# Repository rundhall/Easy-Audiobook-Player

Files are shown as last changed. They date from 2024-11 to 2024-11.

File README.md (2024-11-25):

# Easy Audiobook Player

## Introduction
The **Easy Audiobook Player** is a simple, user-friendly device designed for individuals who face challenges using modern gadgets. Originally created as a Christmas gift for my 94-year-old grandmother, this device is tailored for users with visual or physical impairments, providing an accessible solution for audiobook playback.

---

## Features
- **Single Button Operation**: Simple start/stop functionality.
- **Advanced Controls**:
  - 5-second press: Skip to the next audiobook file.
  - 20-second press: Restart playback from the beginning.
- **Resume Playback**: Automatically resumes from the last played position.

---

## Components

| Component | Quantity | Link | Price  |
|---|---|---|---|
| DC 12V 24V 80W x 2 Audio Amplifier Board | 1 | [Link](https://www.aliexpress.com/item/32823374190.html) | $2.91  |
| Arduino Nano 16MHz ATMEGA328P | 1 | [Link](https://www.aliexpress.com/item/1005006472755752.html) | $3.32  |
| DFPlayer Mini MP3 Module | 1 | [Link](https://www.aliexpress.com/item/4000379417594.html) | $1.63  |
| Game Push Button Switch | 1 | [Link](https://www.aliexpress.com/item/1005006347986280.htm) | $0.50  |
| Wooden Enclosure Box (16x10x9.2 cm) | 1 | [Link](https://www.aliexpress.com/item/1005005854034476.html) | $4.94  |
| Toggle Switch SS22D07 2P2T | 1 | [Link](https://www.aliexpress.com/item/32822779479.html) | $0.91  |
| USB 2.0 A Power Supply Extension Cable | 1 | [Link](https://www.aliexpress.com/item/1005004980471643.html) | $0.56  |
| DC-DC Voltage Regulator Module LM2596S | 1 | [Link](https://www.aliexpress.com/item/1005001691110030.html) | $0.72  |
| GHXAMP Full Range Speakers (4 ohm, 16W) | 2 | [Link](https://www.aliexpress.com/item/1005007219657143.html) | $7.31  |
| Mini Screw Terminal Blocks | 1 | [Link](https://www.aliexpress.com/item/1005005433827504.html) | $0.72  |
| Micro SD Card (max. 32 GB) | 1 | [Link](https://www.aliexpress.com/item/1005001617961938.html) | $2.57  |
| PCB | 1 | Custom | ~$10.00 |

**Total Material Cost**: $36.09

---

## Assembly
### Hardware
1. **Connect Components**: Use a custom PCB or breadboard for wiring the Arduino Nano, DFPlayer Mini, and amplifier board.
2. **Enclosure**:
   - Drill holes for the speaker, button, and cable entry.
   - Mount all components securely in the wooden box.
3. **Power Supply**: Feed the USB power cable through the enclosure and connect to a 5V charger.

### Software
#### Preparing MP3 Files
1. Place your audiobook MP3 files into a `mp3_files` folder.
2. Use the provided Python script (`mp3_to_mp3chunks.bat`) to split files into 5-minute chunks.
3. Copy the output files to the `01` folder on a FAT32-formatted SD card.

#### Programming the Arduino
1. Install [PlatformIO](https://platformio.org/) in Visual Studio Code.
2. Clone the repository and open the `EasyAudiobookPlayer_Arduino` project.
3. Update the `platformio.ini` file to match your Arduino Nano configuration.
4. Upload the code to the Arduino Nano using PlatformIO.

---

## How It Works
- **Playback**: The Arduino controls the DFPlayer Mini to play audio files stored on the SD card.
- **Amplification**: The audio signal is amplified and played through the speakers.
- **Power Management**: A DC-DC converter steps up voltage for the amplifier, while the Arduino and DFPlayer operate on 5V.

---

## Usage Instructions
1. Press the button to start or stop playback.
2. Hold for 5 seconds to skip to the next file.
3. Hold for 20 seconds to reset playback.
4. Enjoy your audiobook!

---

## Conclusion
This Easy Audiobook Player is a thoughtful gift for anyone who values simplicity and accessibility. Whether for a loved one or as a DIY project, it’s a functional and meaningful creation.

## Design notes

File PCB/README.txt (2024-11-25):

# PCB for the Easy Audiobook Player

This is the wiring diagram and PCB plan for Easy Audiobook Player project to make this project even easier to build.

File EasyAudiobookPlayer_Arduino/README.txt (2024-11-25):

EasyAudiobookPlayer project Arduino modul programing. 

## Programming the Arduino Module  

### Requirements  
- A USB cable to connect the Arduino module to your computer.  
- Visual Studio Code with the PlatformIO add-on installed.  
- The EasyAudiobookPlayer Arduino project files from GitHub.  

---

### Steps to Upload the Program  
1. Download the Project  
   - Clone or download the EasyAudiobookPlayer Arduino project files from GitHub.  

2. Install Required Software  
   - Install [Visual Studio Code](https://code.visualstudio.com/).  
   - Open Visual Studio Code and install the PlatformIO add-on.  

3. Open the Project  
   - Open the `EasyAudiobookPlayer_Arduino` directory in Visual Studio Code.  

4. Configure PlatformIO  
     - Open the `platformio.ini` file in the project directory.  
   - Modify the configuration to match your Arduino module type and serial port:  
	"[env:nanoatmega328]
	platform = atmelavr
	board = nanoatmega328
	framework = arduino
	monitor_speed = 115200
	lib_deps = 	
		xoseperez/DebounceEvent@^2.0.5
		prosenb/EEPROMWearLevel@^2.1.0
		dfrobot/DFRobotDFPlayerMini@^1.0.6 “
 - Replace ` nanoatmega328` with the correct Arduino model (e.g., `pro16MHzatmega328`).  
 - Add this line: upload_port = your_serial_port if you know the serial port belongs to the Arduiono. Replace `your_serial_port` with the appropriate COM port (e.g., `COM3` on Windows).  

5. Modify the Source Code (Optional)  
   - If needed, edit the file `EasyAudiobookPlayer_Arduino\src\main.cpp` to customize the functionality.  

6. Upload the Program  
   - Connect the Arduino module to your computer via USB.  
   - In Visual Studio Code, click the PlatformIO: Upload button or use the shortcut to upload the program to the Arduino.  

---

### Program Overview  
The program is structured as follows:  

1. Initialization in `setup()`  
   - The MP3 player module is initialized.  
   - Button press functionality is configured.  

2. Looping in `loop()`  
   - Continuously monitors:  
     - Button presses:  
       - Toggles between play and pause modes.  
     - MP3 playback status:  
       - If an MP3 finishes, the program:  
         - Saves the current MP3 sequence number to the EEPROM.  
         - Ensures playback can resume from this sequence number upon restarting the device.  

---

### Notes  
- Ensure the Arduino module is compatible with the selected settings in the `platformio.ini` file.  
- The program uses the EEPROM to save and retrieve the MP3 sequence number, allowing it to resume playback seamlessly after a power cycle or reset.  

--- 

This README should guide you through the upload process and provide an understanding of the program's functionality. Let me know if you need further clarifications or enhancements!

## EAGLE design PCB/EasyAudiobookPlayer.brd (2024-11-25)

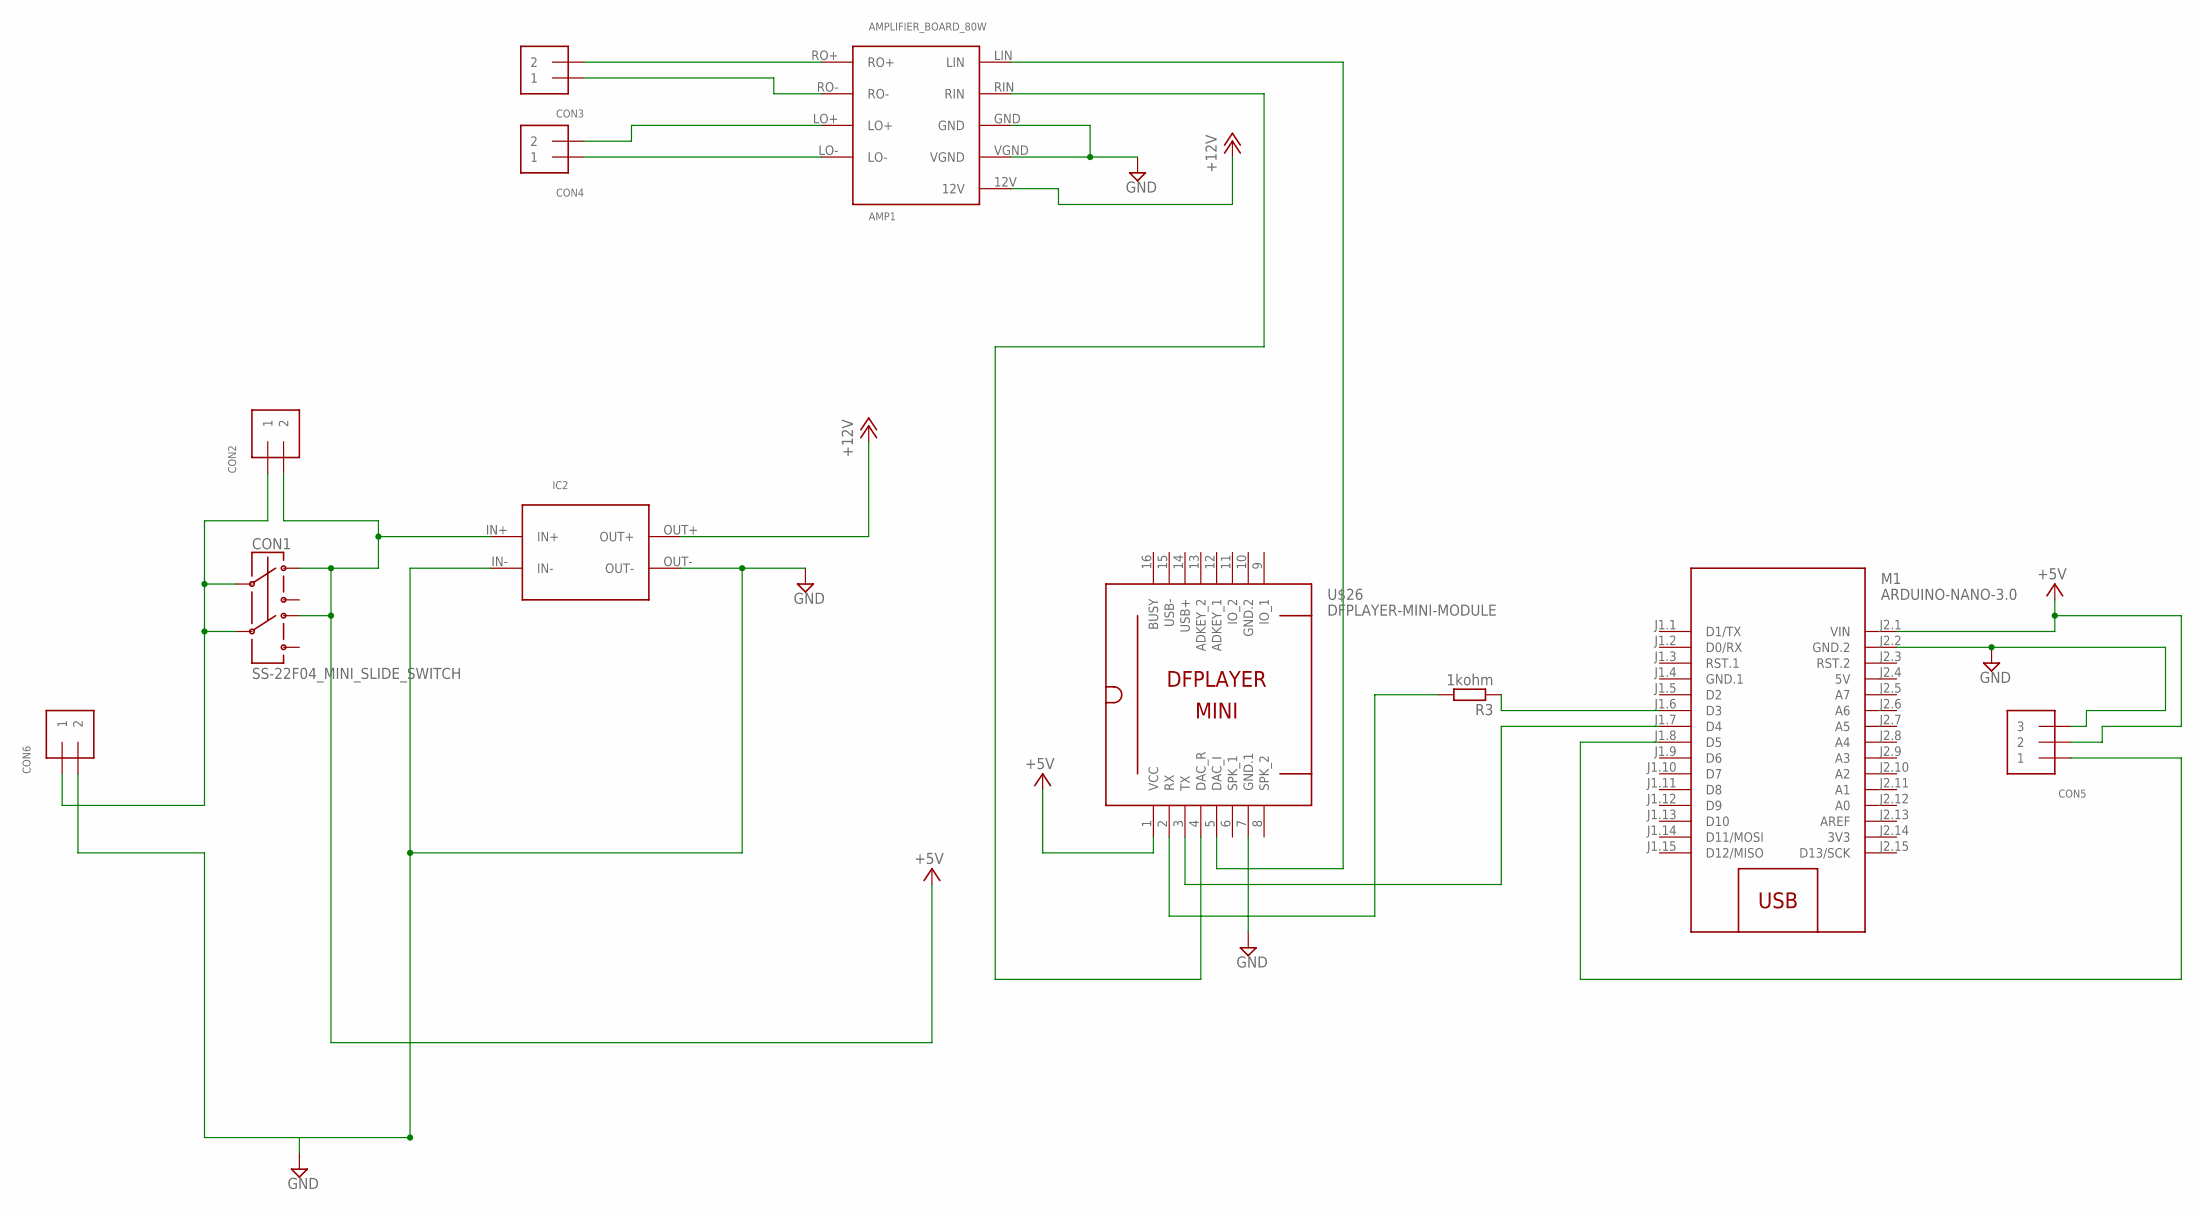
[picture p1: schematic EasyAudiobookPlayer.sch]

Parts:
AMP1: AMPLIFIER_BOARD_80W
CON1: SS-22F04_MINI_SLIDE_SWITCH
CON2, CON3, CON4, CON6: 1X2_5MM_TERMINAL_BLOCK
CON5: 1X3_5MM_TERMINAL_BLOCK
IC2: XL6009_STEP_UP_CONVERTER_MODULE
M1: ARDUINO-NANO-3.0
R3: 1kohm; M1206
U$26: DFPLAYER-MINI-MODULE

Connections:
3V3: M1.J2.14 (3V3)
5V: M1.J2.4 (5V)
+5V: CON1.O1_2, CON1.O2_2, CON2.2, CON5.2, IC2.IN+, M1.J2.1 (VIN), U$26.1 (VCC)
+12V: AMP1.12V, IC2.OUT+
GND: AMP1.GND, AMP1.VGND, CON5.3, CON6.2, IC2.IN-, IC2.OUT-, M1.J2.2 (GND.2), U$26.7 (GND.1)
GND.1: M1.J1.4 (GND.1)
GND.2: U$26.10 (GND.2)
unnamed: CON1.I1_1, CON1.I2_1, CON2.1, CON6.1
unnamed: AMP1.RO+, CON3.2
unnamed: AMP1.RO-, CON3.1
unnamed: AMP1.LO+, CON4.2
unnamed: AMP1.LO-, CON4.1
unnamed: M1.J1.6 (D3), R3.1
unnamed: R3.2, U$26.2 (RX)
unnamed: M1.J1.7 (D4), U$26.3 (TX)
unnamed: AMP1.RIN, U$26.4 (DAC_R)
unnamed: AMP1.LIN, U$26.5 (DAC_I)
unnamed: CON5.1, M1.J1.8 (D5)

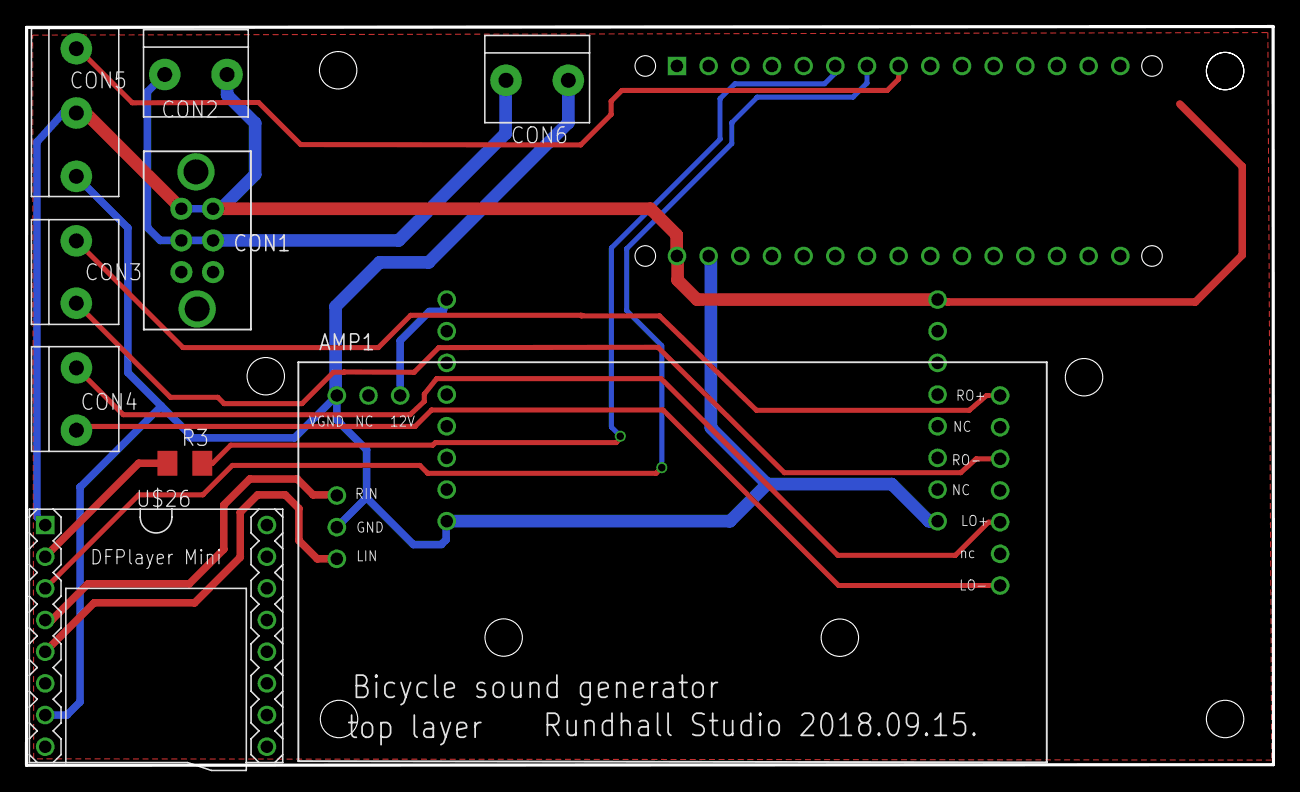
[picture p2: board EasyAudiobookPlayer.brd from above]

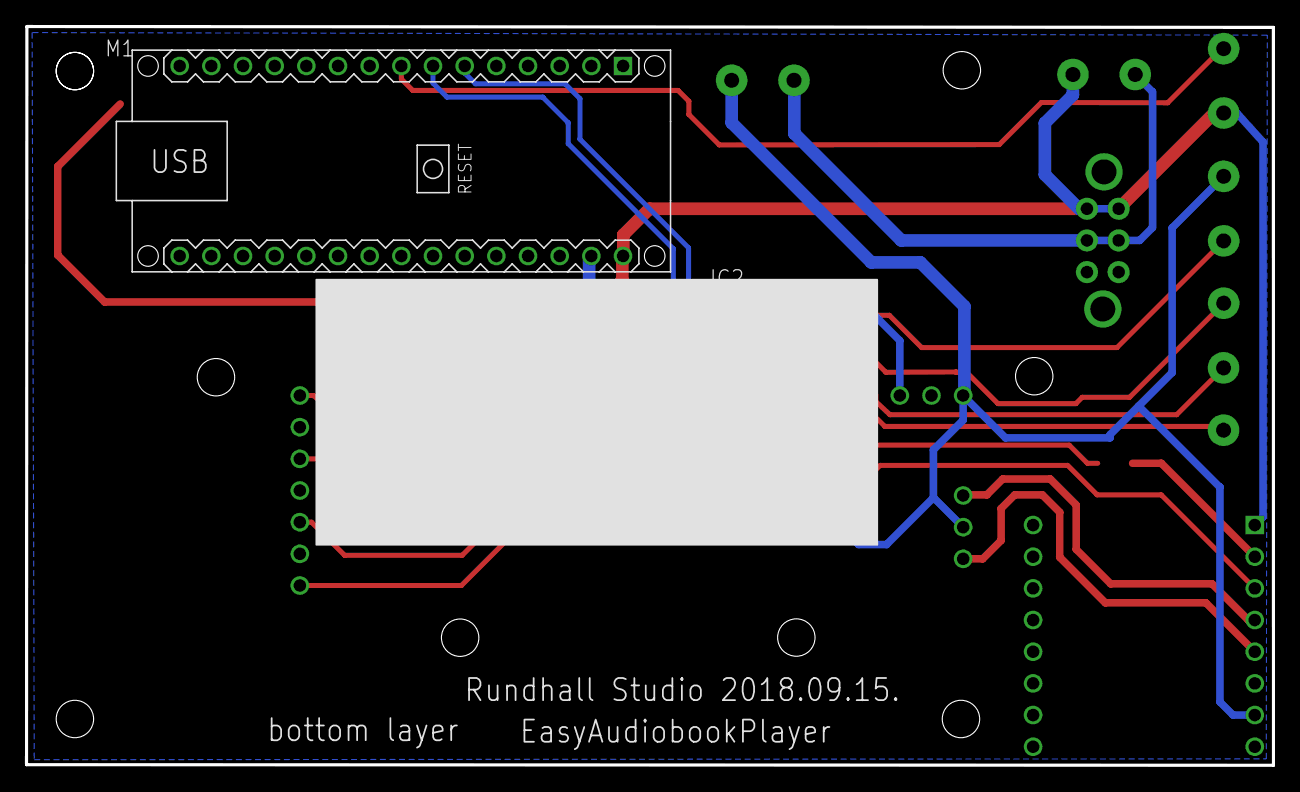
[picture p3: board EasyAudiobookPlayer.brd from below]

Board: 4 copper layers, 100.0 x 59.3 mm, 11 parts (2 on the bottom side), 14 nets.

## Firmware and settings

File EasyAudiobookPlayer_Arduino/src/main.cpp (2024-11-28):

#include "Arduino.h"
#include "SoftwareSerial.h"
#include "DFRobotDFPlayerMini.h"
#include <EEPROM.h>
#include <DebounceEvent.h>
#include <EEPROMWearLevel.h>
#define BUTTON_PIN 5
#define LED 13

SoftwareSerial mySoftwareSerial(4, 3); // RX, TX
DFRobotDFPlayerMini myDFPlayer;
// See https://github.com/PRosenb/EEPROMWearLevel
#define EEPROM_LAYOUT_VERSION 0
#define AMOUNT_OF_INDEXES 2
#define INDEX_CONFIGURATION_VAR1 0



bool isPlaying = false;
int currentFile = 1;


void saveState() {
  EEPROMwl.put(INDEX_CONFIGURATION_VAR1, currentFile);
  Serial.print(F("Saved current file: "));
  Serial.println(currentFile);
}

// Callback function for the button
void buttonCallback(uint8_t pin, uint8_t event, uint8_t count, uint16_t length) {
  Serial.print("Event : "); Serial.print(event);
  Serial.print(" Count : "); Serial.print(count);
  Serial.print(" Length: "); Serial.print(length);
  Serial.println();
  if (length > 20000 ) {          //Restart audiooks
      Serial.print("CurrentFile was: "); Serial.print(currentFile);
      currentFile = 1;
      Serial.print(" New value : "); Serial.print(currentFile);
      Serial.println();
      myDFPlayer.pause();
      myDFPlayer.playLargeFolder(1,currentFile);
      saveState();
  }
  else {
    if (length > 5000 ) {       //Next file

        currentFile = currentFile + 1; // Move to the next file
        saveState();

        myDFPlayer.playLargeFolder(1,currentFile);
        Serial.print(" New currentFile : "); Serial.print(currentFile);
        Serial.println();
    }
    else{
      if (length > 200 ) { // Button press detected pause or play
        if (isPlaying) {
          myDFPlayer.pause();
          isPlaying = false;
          digitalWrite(LED, LOW);
        } else {
          myDFPlayer.start();
          isPlaying = true;
          digitalWrite(LED, HIGH);
        }
      }
    }
  }
}

// Initialize the DebounceEvent instance
DebounceEvent button(BUTTON_PIN, buttonCallback, BUTTON_PUSHBUTTON | BUTTON_DEFAULT_HIGH | BUTTON_SET_PULLUP);



void loadState() {
  EEPROMwl.get(INDEX_CONFIGURATION_VAR1, currentFile);
  if (currentFile < 1 || currentFile > 9999 ) {
    currentFile = 1; // Default to the first file if the EEPROM value is invalid.
  }
  Serial.print(F("Loaded current file: "));
  Serial.println(currentFile);
}

void setup() {
  mySoftwareSerial.begin(9600);
  Serial.begin(115200);
  pinMode(LED, OUTPUT);
  EEPROMwl.begin(EEPROM_LAYOUT_VERSION, AMOUNT_OF_INDEXES);   
  Serial.println(F("Initializing DFPlayer ... (May take 3~5 seconds)"));

  if (!myDFPlayer.begin(mySoftwareSerial)) {
    Serial.println(F("Unable to begin:"));
    Serial.println(F("1. Please recheck the connection!"));
    Serial.println(F("2. Please insert the SD card!"));
    while (true);
  }
  Serial.println(F("DFPlayer Mini online."));

  myDFPlayer.volume(30); // Set volume value. From 0 to 30

  loadState();
  myDFPlayer.playLargeFolder(1,currentFile); // Start playing the saved file
  isPlaying = true;
}

void loop() {
  button.loop();

  if (myDFPlayer.available()) {
    uint8_t type = myDFPlayer.readType();
    //int value = myDFPlayer.read();
    if (type == DFPlayerPlayFinished) {
      Serial.print(F("Finished playing file read: "));
      Serial.println(currentFile);
      currentFile = currentFile + 1; // Move to the next file
      saveState();
      myDFPlayer.playLargeFolder(1,currentFile);
    }
  }
}

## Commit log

2024-11-25 Dir change
    [EasyAudiobookPlayer.brd, EasyAudiobookPlayer.sch]
2024-11-28 next track bug fix
    [main.cpp]

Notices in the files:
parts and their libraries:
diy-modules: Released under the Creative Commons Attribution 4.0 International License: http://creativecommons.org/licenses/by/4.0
